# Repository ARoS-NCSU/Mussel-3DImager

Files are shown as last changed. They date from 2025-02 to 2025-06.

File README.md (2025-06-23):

# Mussel 3D Imager

We leverage advanced 3D reconstruction techniques to enhance the accuracy of AI-based mussel analysis. Specifically, we utilize Neural Radiance Fields (NeRF), a cutting-edge 3D reconstruction tool, to generate detailed 3D models of mussel valve configurations and behavioral patterns. NeRF reconstructs 3D scenes and objects from a sparse set of 2D images.

To facilitate image capture, we developed a custom data collection system capable of imaging mussels from multiple angles. This system includes a turntable constructed from foam board, marked along the edges for reference, with a central mounting area for the mussels. A servo motor, controlled by an ESP32 microcontroller, rotates the turntable in small increments, while an ESP32 camera captures images at each step. The captured images, along with rotation degree data and timestamps, are stored on a Secure Digital (SD) card.

Additionally, several key components, such as the camera holder and turntable base, are 3D-printed. The collected images are then used to train a NeRF model using the Python-based Nerfstudio framework, and the generated 3D models can be visualized through the Nerfstudio API.

## Assembly Instructions:

You will need: 

1. A 1/2" PVC pipe
2. 3/16" thick foam baord to construct base plate 
3. Printed 3D parts, located in the 3D Parts folder

Construct the base plate by cutting a 1ft diameter circle out of the foam board. Create the rim for the plate by cutting out a 3.5in by 3ft rectangle. Score it with a blade to allow it to form a ring as seen in the image below. Attach the Dis+Base+Bottom part to the bottom of the plate and the Disc+Base+Top file on top of the plate, and secure them together with screws. Glue the arm of the Servo motor to the center of the Dis+Base+Bottom part. place the servo into the slot in the Base+Part+1 part. 

The Base+Part+1 and Base+Part+2 should be secured to a surface using tape or clamps when running, as they will topple over if not secured. 

ESP32 Mount Instructions:

Super glue the ESP32+-+Joint+Attachment to the back of the ESP32+-+Mount. The PVC+Suport+with+Connector should fit snugly into the gap of the ESP32+-+Joint+Attachment. Use a screw and a nut to keep it in place. The ESP32 Mount should be able to rotate tightly. Attach it to the PVC pipe, using zip ties to keep it secure. 

Read the README_code.txt file for instructions on programming.

## 3D reconstruction instructions using NeRFStudio:
This section provides instructions for performing 3D reconstruction using Nerfstudio.
### Installation
To set up the environment, follow the installation instructions from the official Nerfstudio documentation: https://docs.nerf.studio/quickstart/installation.html
### Data Processing
Once installed, process your image dataset by running the following command:
```bash
ns-process-data images --data {DATA_PATH} --output-dir {PROCESSED_DATA_DIR}
```
Replace {DATA_PATH} with the path to your dataset and {PROCESSED_DATA_DIR} with the desired output directory for processed data.
### Training
Train the Nerfacto model using the processed data:
```bash
ns-train nerfacto --data {PROCESSED_DATA_DIR}
```
### Evaluation
To evaluate the trained model, use the following command:
```bash
ns-eval --load-config={PATH_TO_CONFIG} --output-path=output.json
```
Replace {PATH_TO_CONFIG} with the path to your configuration file.
### Results
The evaluation results will be saved in output.json.

For more details, refer to the Nerfstudio documentation.
## Mussel 3D reconstruction Output:
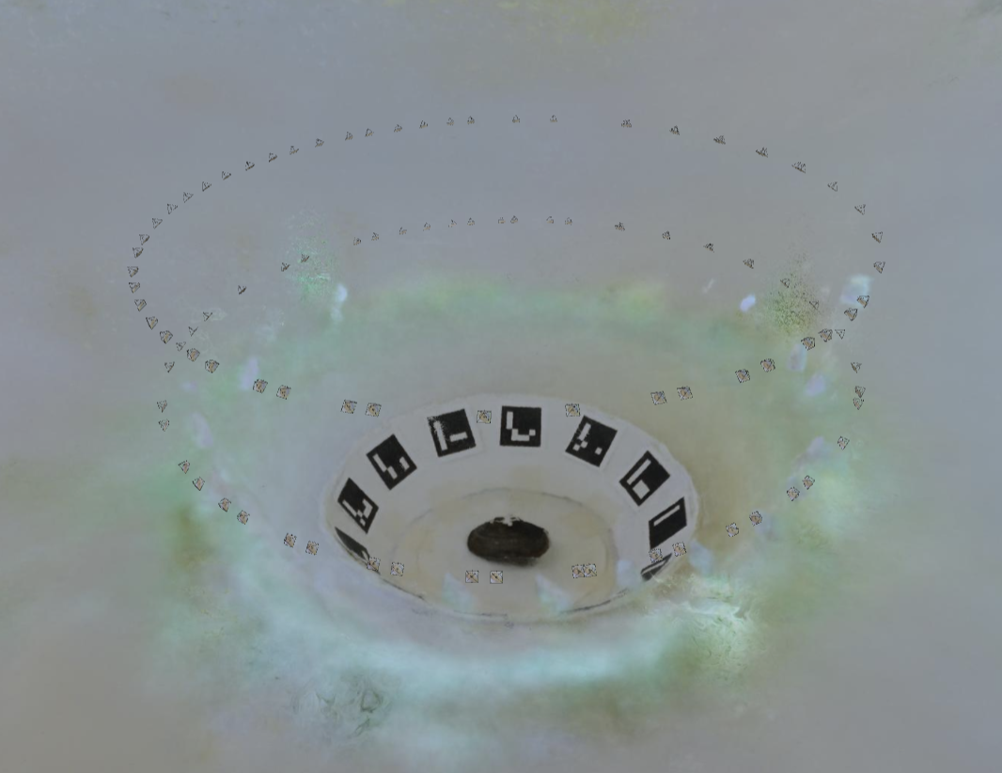
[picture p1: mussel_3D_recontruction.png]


## ESP32 based imaging system:
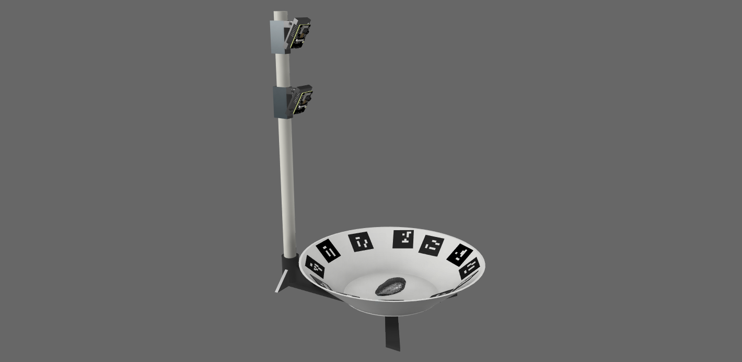
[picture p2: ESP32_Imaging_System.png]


## Mussel ESP32 3D Reconstruction
Video - https://www.youtube.com/watch?v=Asff8yX_VgY

## Citation

If you use this work in your research, please cite:

```bibtex
@inproceedings{sanap2025ai,
  author    = {Mayur Sanap and Arman Badalamenti and Devadharshini Ayyappan and Sanjana Banerjee and Diana Milena Urieta and Caren Cooper and Michael Daniele and James Reynolds and Jay F. Levine and Alper Bozkurt and Edgar Lobaton},
  title     = {AI-Driven Mussel Behavior Monitoring Using an Accessible 3D Imaging System},
  booktitle = {Proceedings of the 2025 ASEE Annual Conference \& Exposition},
  year      = {2025},
  address   = {Montreal, QC},
  month     = {June 22--25},
  organization = {ASEE}
}
```

## Contact Us

If you have any questions or suggestions, feel free to reach out:

- Mayur Sanap - msanap@ncsu.edu
- Dr. Edgar Lobaton - edgar.lobaton@ncsu.edu

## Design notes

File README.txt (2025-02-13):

-------- INTRODUCTION --------

The 'ESP32_cam_google_drive.ino' file folder will allow you to run a program on your ESP32-CAM that will connect your ESP32-CAM to the internet, connect to google, periodically take photos and send them to a google drive folder. 'The ESP32_cam_google_drive_and_servo_motor.ino' file folder does the same thing, except it also rotates a servo motor between taking photos. 

The 'ESP32_CAM_GS.txt' file is a google script that will allow the ESP32-CAM to save photos directly to your google drive. 

-------- SET UP --------

Before running the .ino files, you must create the google script. To do this, do the following. 

1. Go to https://script.google.com/home/

2. Click 'New Project'

3. Paste the contents of 'ESP32_CAM_GS.txt' into the code space. Edit the time zone to yours and change the value of the folderName constant to the name of the folder in google derive that you would like to save your photos to. 

4. Click 'Deploy,' then click 'New Deployment.'

5. Select type 'Web App,' then change Who has access to 'Anyone.'

6. Click Deploy and authorize with your google id when prompted. 

7. Copy the deployment ID. This will be used in the .ino scripts

-------- RUNNING THE INO FILES --------

Save the the 'ESP32_cam_google_drive_and_servo_motor.ino' and 'ESP32_cam_google_drive.ino' file folders to your local device and open them using your IDE. In the .ino files, find the following lines of code:

const char* ssid = "****";
const char* password = "****";

ssid shold be set to your networks ssid and password should be set to your network's password. 

Below that, there will be the following lines of code:

String myDeploymentID = "Deployment ID";
String myMainFolderName = "Folder Name";

Paste your google script's deployment ID and the corresponding folder name.

Upload the two projects to two different ESP32-CAMs

-------- CONNECTINGE THE SERVO --------

The ESP32-CAM that the 'ESP32_cam_google_drive_and_servo_motor.ino' file was uploaded to should be connected to a micro servo motor. Connect the servo's positive wire to the ESP32-CAM's 3.3V pin, connect the servo's ground wire to the ESP32-CAM's ground pin, and connect the servo's signal pin to GPIO pin 13. 

-------- RUNNING THE CODE --------

The code will run automatically when connected to power and start taking photos and sending them to google drive.

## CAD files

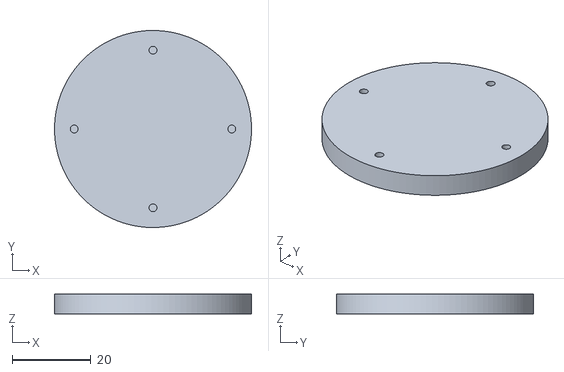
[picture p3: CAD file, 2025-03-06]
3D Parts/Disk+Base+Top.stl
50.0 x 50.0 x 5.00

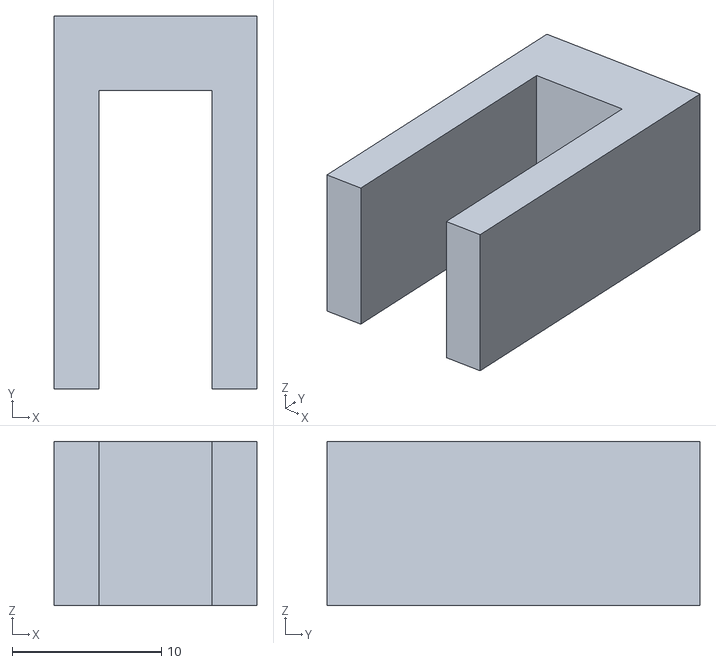
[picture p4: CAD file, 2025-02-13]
3D Parts/ESP32+-+Clip+-+Top.stl
13.6 x 25.0 x 11.0

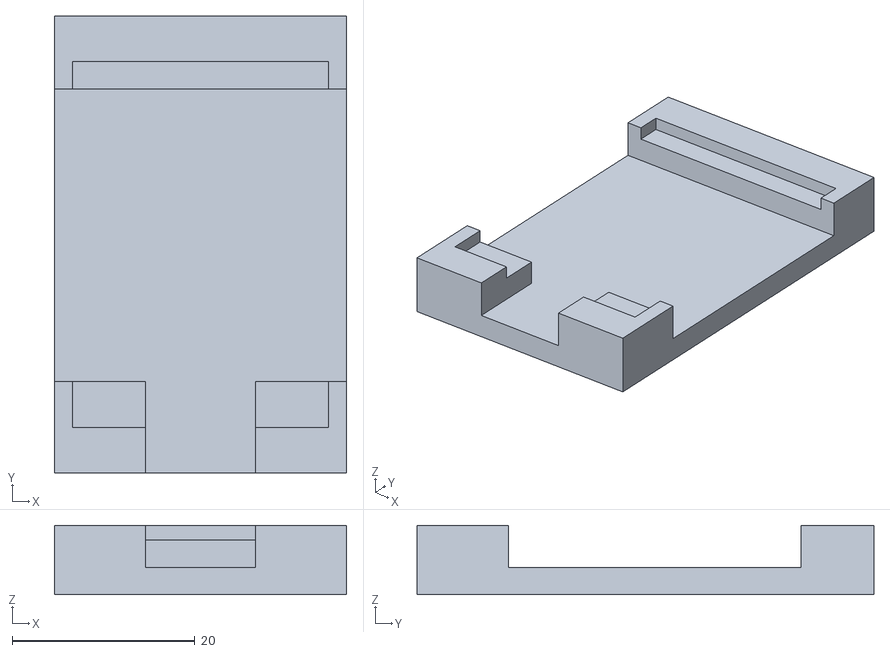
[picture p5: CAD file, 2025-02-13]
3D Parts/ESP32+-+Mount.stl
32.0 x 50.0 x 7.60

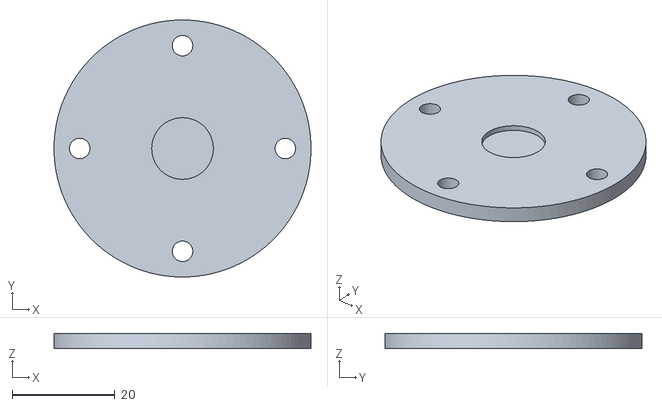
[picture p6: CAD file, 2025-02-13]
3D Parts/Disc+Base+Bottom.stl
50.0 x 50.0 x 3.00

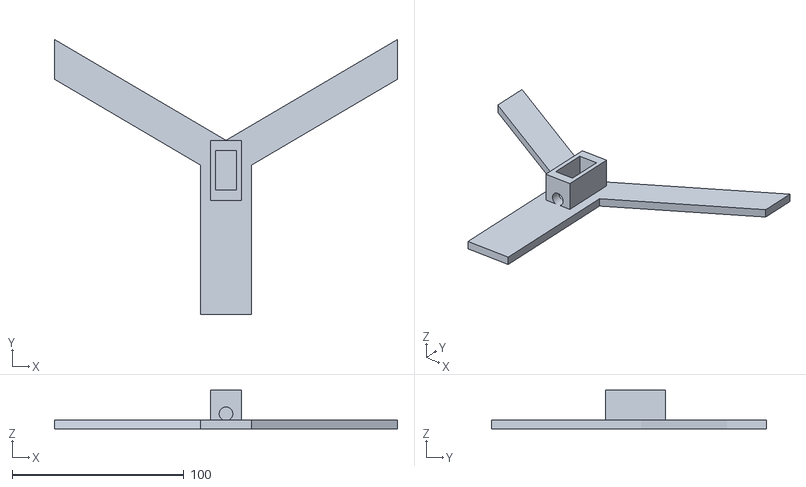
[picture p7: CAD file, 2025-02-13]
3D Parts/Base+Part+1.stl
200.0 x 160.4 x 22.5

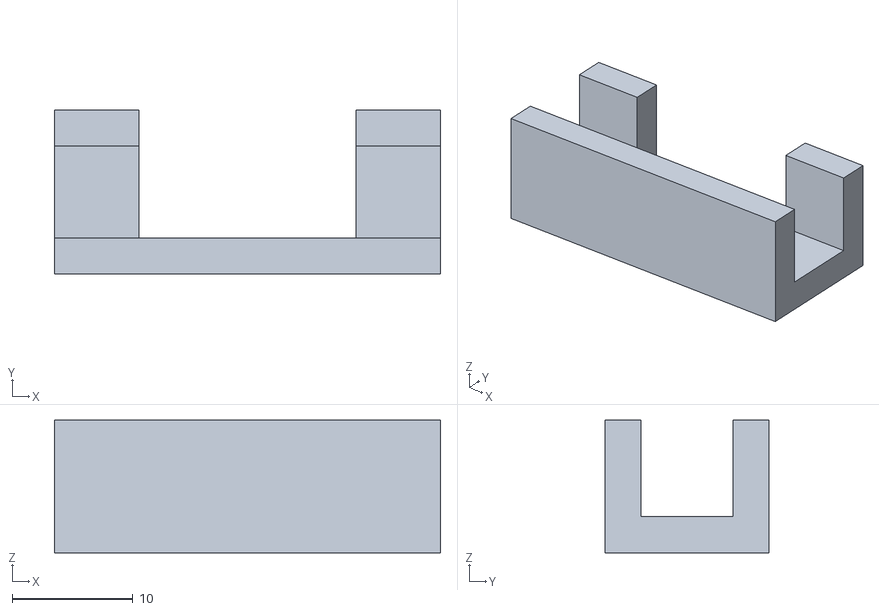
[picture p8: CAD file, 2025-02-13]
3D Parts/ESP32+-+Clip+-+Bottom.stl
32.0 x 13.6 x 11.0

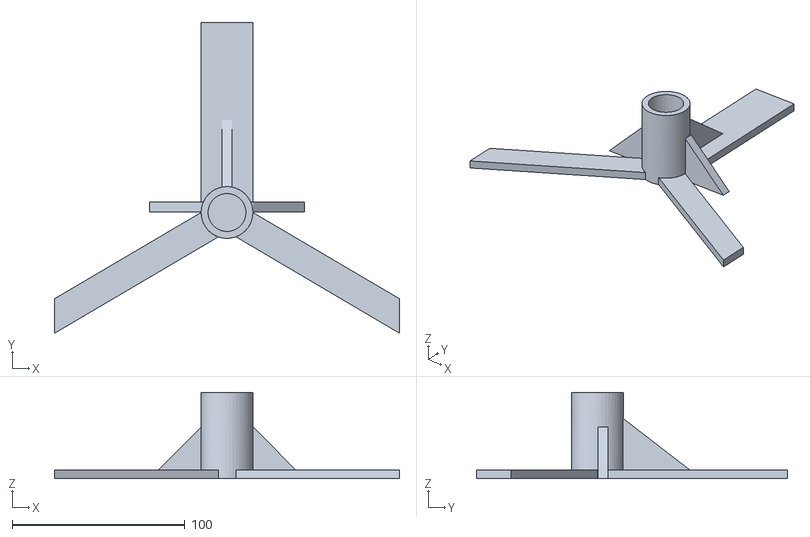
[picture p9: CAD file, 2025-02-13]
3D Parts/Base+Part+2.stl
200.0 x 180.0 x 50.0

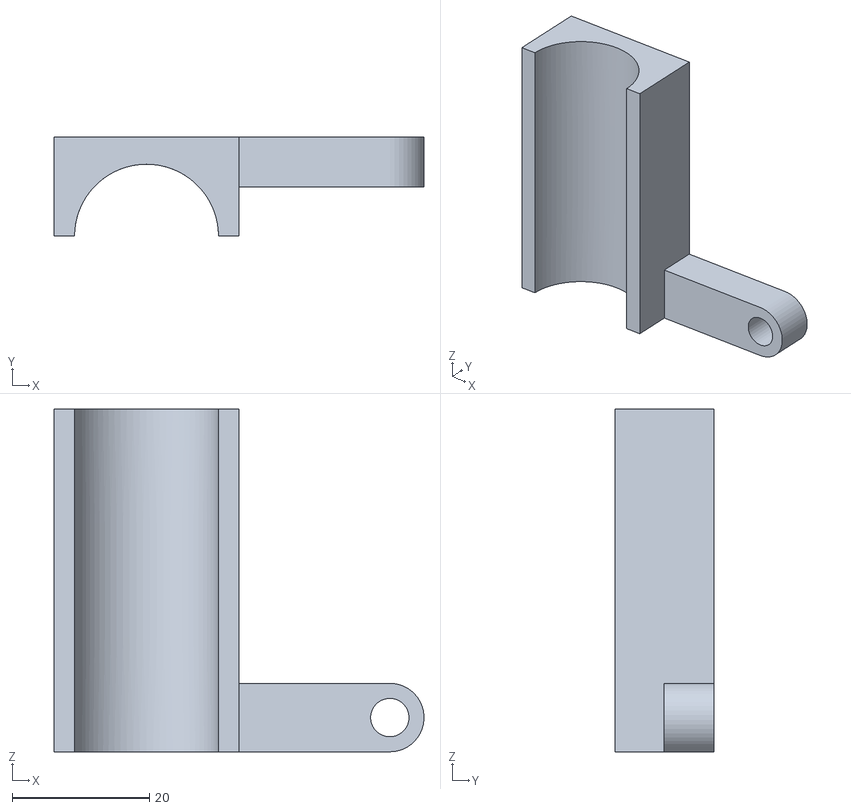
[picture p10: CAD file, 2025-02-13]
3D Parts/PVC+Suport+with+Connector.stl
54.0 x 14.5 x 50.0

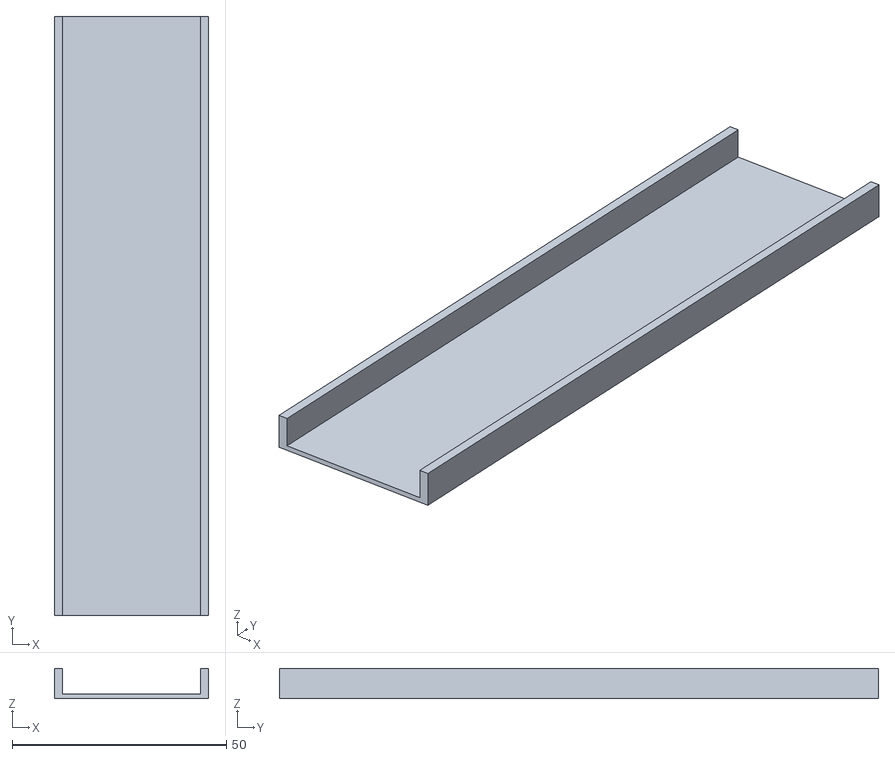
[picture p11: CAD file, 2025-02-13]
3D Parts/Base+Tray.stl
36.0 x 139.6 x 7.00

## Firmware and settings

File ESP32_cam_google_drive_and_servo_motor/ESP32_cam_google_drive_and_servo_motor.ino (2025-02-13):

//======================================== Included libraries and files
#include <WiFi.h>
#include <WiFiClientSecure.h>
#include <ESP32Servo.h>
#include "soc/soc.h"
#include "soc/rtc_cntl_reg.h"
#include "Base64.h"
#include "esp_camera.h"

//======================================== Define pins
#define PWDN_GPIO_NUM     32
#define RESET_GPIO_NUM    -1
#define XCLK_GPIO_NUM      0
#define SIOD_GPIO_NUM     26
#define SIOC_GPIO_NUM     27

#define Y9_GPIO_NUM       35
#define Y8_GPIO_NUM       34
#define Y7_GPIO_NUM       39
#define Y6_GPIO_NUM       36
#define Y5_GPIO_NUM       21
#define Y4_GPIO_NUM       19
#define Y3_GPIO_NUM       18
#define Y2_GPIO_NUM        5
#define VSYNC_GPIO_NUM    25
#define HREF_GPIO_NUM     23
#define PCLK_GPIO_NUM     22
#define SERVO_1           13
#define TURN_TIME         82    // TURN_TIME is time in ms servo will rotate for
#define SERVO_STOP        95    // Servo Stops when 95 is written to it
#define SERVO_MOVE        60    // Value between 0 and 95. Closer to 0 rotates faster 

//======================================== 

#define FLASH_LED 4


Servo servo1;                 // Create Servo object

//======================================== Enter your WiFi ssid and password.
const char* ssid = "****";
const char* password = "****";
//======================================== 

//======================================== Replace with your "Deployment ID" and Folder Name.
String myDeploymentID = "Deployment ID";
String myMainFolderName = "Folder Name";
//======================================== 

//======================================== Variables for Timer/Millis.
unsigned long previousMillis = 0; 
const int Interval = 20000; //--> Capture and Send a photo every 20 seconds.
//======================================== 

// Variable to set capture photo with LED Flash.
// Set to "false", then the Flash LED will not light up when capturing a photo.
// Set to "true", then the Flash LED lights up when capturing a photo.
bool LED_Flash_ON = false;

// Initialize WiFiClientSecure.
WiFiClientSecure client;

//________________________________________________________________________________ Test_Con()
// This subroutine is to test the connection to "script.google.com".
void Test_Con() {
  const char* host = "script.google.com";
  while(1) {
    Serial.println("-----------");
    Serial.println("Connection Test...");
    Serial.println("Connect to " + String(host));
  
    client.setInsecure();
  
    if (client.connect(host, 443)) {
      Serial.println("Connection successful.");
      Serial.println("-----------");
      client.stop();
      break;
    } else {
      Serial.println("Connected to " + String(host) + " failed.");
      Serial.println("Wait a moment for reconnecting.");
      Serial.println("-----------");
      client.stop();
    }
  
    delay(1000);
  }
}
//________________________________________________________________________________ 




//________________________________________________________________________________ SendCapturedPhotos()
// Subroutine for capturing and sending photos to Google Drive.
void SendCapturedPhotos() {
  const char* host = "script.google.com";
  Serial.println();
  Serial.println("-----------");
  Serial.println("Connect to " + String(host));
  
  client.setInsecure();

  //---------------------------------------- The Flash LED blinks once to indicate connection start.
  digitalWrite(FLASH_LED, HIGH);
  delay(100);
  digitalWrite(FLASH_LED, LOW);
  delay(100);
  //---------------------------------------- 

  //---------------------------------------- The process of connecting, capturing and sending photos to Google Drive.
  if (client.connect(host, 443)) {
    Serial.println("Connection successful.");
    
    if (LED_Flash_ON == true) {
      digitalWrite(FLASH_LED, HIGH);
      delay(100);
    }

    //.............................. Taking a photo.
    Serial.println();
    Serial.println("Taking a photo...");
    
    for (int i = 0; i <= 3; i++) {
      camera_fb_t * fb = NULL;
      fb = esp_camera_fb_get();
       if(!fb) {
          Serial.println("Camera capture failed");
          Serial.println("Restarting the ESP32 CAM.");
          delay(1000);
          ESP.restart();
          return;
        } 
      esp_camera_fb_return(fb);
      delay(200);
    }
  
    camera_fb_t * fb = NULL;
    fb = esp_camera_fb_get();
    if(!fb) {
      Serial.println("Camera capture failed");
      Serial.println("Restarting the ESP32 CAM.");
      delay(1000);
      ESP.restart();
      return;
    } 
  
    if (LED_Flash_ON == true) digitalWrite(FLASH_LED, LOW);
    
    Serial.println("Taking a photo was successful.");

    //.............................. 

    //.............................. Sending image to Google Drive.
    Serial.println();
    Serial.println("Sending image to Google Drive.");
    Serial.println("Size: " + String(fb->len) + "byte");
    
    String url = "/macros/s/" + myDeploymentID + "/exec?folder=" + myMainFolderName;

    client.println("POST " + url + " HTTP/1.1");
    client.println("Host: " + String(host));
    client.println("Transfer-Encoding: chunked");
    client.println();

    int fbLen = fb->len;
    char *input = (char *)fb->buf;
    int chunkSize = 3 * 1000; //--> must be multiple of 3.
    int chunkBase64Size = base64_enc_len(chunkSize);
    char output[chunkBase64Size + 1];

    Serial.println();
    int chunk = 0;
    for (int i = 0; i < fbLen; i += chunkSize) {
      int l = base64_encode(output, input, min(fbLen - i, chunkSize));
      client.print(l, HEX);
      client.print("\r\n");
      client.print(output);
      client.print("\r\n");
      delay(100);
      input += chunkSize;
      Serial.print(".");
      chunk++;
      if (chunk % 50 == 0) {
        Serial.println();
      }
    }
    client.print("0\r\n");
    client.print("\r\n");

    esp_camera_fb_return(fb);
    //.............................. 

    //.............................. Waiting for response.
    Serial.println("Waiting for response.");
    long int StartTime = millis();
    while (!client.available()) {
      Serial.print(".");
      delay(100);
      if ((StartTime + 10 * 1000) < millis()) {
        Serial.println();
        Serial.println("No response.");
        break;
      }
    }
    Serial.println();
    while (client.available()) {
      Serial.print(char(client.read()));
    }
    //.............................. 

    //.............................. Flash LED blinks once as an indicator of successfully sending photos to Google Drive.
    digitalWrite(FLASH_LED, HIGH);
    delay(500);
    digitalWrite(FLASH_LED, LOW);
    delay(500);
    //.............................. 
  }
  else {
    Serial.println("Connected to " + String(host) + " failed.");
    
    //.............................. Flash LED blinks twice as a failed connection indicator.
    digitalWrite(FLASH_LED, HIGH);
    delay(500);
    digitalWrite(FLASH_LED, LOW);
    delay(500);
    digitalWrite(FLASH_LED, HIGH);
    delay(500);
    digitalWrite(FLASH_LED, LOW);
    delay(500);
    //.............................. 
  }
  //---------------------------------------- 

  Serial.println("-----------");

  client.stop();
}
//________________________________________________________________________________ 

//________________________________________________________________________________ VOID SETUP()
void setup() {
  // put your setup code here, to run once:
  
  // Disable brownout detector.
  servo1.attach(SERVO_1);
  WRITE_PERI_REG(RTC_CNTL_BROWN_OUT_REG, 0);
  
  Serial.begin(115200);
  Serial.println();
  delay(1000);

  pinMode(FLASH_LED, OUTPUT);
  
  // Setting the ESP32 WiFi to station mode.
  Serial.println();
  Serial.println("Setting the ESP32 WiFi to station mode.");
  WiFi.mode(WIFI_STA);

  //---------------------------------------- The process of connecting ESP32 CAM with WiFi Hotspot / WiFi Router.
  Serial.println();
  Serial.print("Connecting to : ");
  Serial.println(ssid);
  WiFi.begin(ssid, password);
  
  // The process timeout of connecting ESP32 CAM with WiFi Hotspot / WiFi Router is 20 seconds.
  // If within 20 seconds the ESP32 CAM has not been successfully connected to WiFi, the ESP32 CAM will restart.
 
  int connecting_process_timed_out = 40; //--> 20 = 20 seconds.
  connecting_process_timed_out = connecting_process_timed_out * 2;
  while (WiFi.status() != WL_CONNECTED) {
    Serial.print(".");
    digitalWrite(FLASH_LED, HIGH);
    delay(250);
    digitalWrite(FLASH_LED, LOW);
    delay(250);
    if(connecting_process_timed_out > 0) connecting_process_timed_out--;
    if(connecting_process_timed_out == 0) {
      Serial.println();
      Serial.print("Failed to connect to ");
      Serial.println(ssid);
      Serial.println("Restarting the ESP32 CAM.");
      delay(1000);
      ESP.restart();
    }
  }

  digitalWrite(FLASH_LED, LOW);
  
  Serial.println();
  Serial.print("Successfully connected to ");
  Serial.println(ssid);
  //Serial.print("ESP32-CAM IP Address: ");
  //Serial.println(WiFi.localIP());
  //---------------------------------------- 

  //---------------------------------------- Set the camera ESP32 CAM.
  Serial.println();
  Serial.println("Set the camera ESP32 CAM...");
  
  camera_config_t config;
  config.ledc_channel = LEDC_CHANNEL_0;
  config.ledc_timer = LEDC_TIMER_0;
  config.pin_d0 = Y2_GPIO_NUM;
  config.pin_d1 = Y3_GPIO_NUM;
  config.pin_d2 = Y4_GPIO_NUM;
  config.pin_d3 = Y5_GPIO_NUM;
  config.pin_d4 = Y6_GPIO_NUM;
  config.pin_d5 = Y7_GPIO_NUM;
  config.pin_d6 = Y8_GPIO_NUM;
  config.pin_d7 = Y9_GPIO_NUM;
  config.pin_xclk = XCLK_GPIO_NUM;
  config.pin_pclk = PCLK_GPIO_NUM;
  config.pin_vsync = VSYNC_GPIO_NUM;
  config.pin_href = HREF_GPIO_NUM;
  config.pin_sscb_sda = SIOD_GPIO_NUM;
  config.pin_sscb_scl = SIOC_GPIO_NUM;
  config.pin_pwdn = PWDN_GPIO_NUM;
  config.pin_reset = RESET_GPIO_NUM;
  config.xclk_freq_hz = 20000000;
  config.pixel_format = PIXFORMAT_JPEG;
  
  // init with high specs to pre-allocate larger buffers
  if(psramFound()){
    config.frame_size = FRAMESIZE_UXGA;
    config.jpeg_quality = 10;  //0-63 lower number means higher quality
    config.fb_count = 2;
  } else {
    config.frame_size = FRAMESIZE_SVGA;
    config.jpeg_quality = 8;  //0-63 lower number means higher quality
    config.fb_count = 1;
  }
  
  // camera init
  esp_err_t err = esp_camera_init(&config);
  if (err != ESP_OK) {
    Serial.printf("Camera init failed with error 0x%x", err);
    Serial.println();
    Serial.println("Restarting the ESP32 CAM.");
    delay(1000);
    ESP.restart();
  }

  sensor_t * s = esp_camera_sensor_get();

  // Selectable camera resolution details :
  // -UXGA   = 1600 x 1200 pixels
  // -SXGA   = 1280 x 1024 pixels
  // -XGA    = 1024 x 768  pixels
  // -SVGA   = 800 x 600   pixels
  // -VGA    = 640 x 480   pixels
  // -CIF    = 352 x 288   pixels
  // -QVGA   = 320 x 240   pixels
  // -HQVGA  = 240 x 160   pixels
  // -QQVGA  = 160 x 120   pixels
  s->set_framesize(s, FRAMESIZE_SXGA);  //--> UXGA|SXGA|XGA|SVGA|VGA|CIF|QVGA|HQVGA|QQVGA

  Serial.println("Setting the camera successfully.");
  Serial.println();

  delay(1000);

  Test_Con();

  Serial.println();
  Serial.println("ESP32-CAM captures and sends photos to the server every 20 seconds.");
  Serial.println();
  delay(2000);
}
//________________________________________________________________________________ 

//________________________________________________________________________________ VOID LOOP()
void loop() {
  // put your main code here, to run repeatedly:

  //---------------------------------------- Timer/Millis to capture and send photos to Google Drive every 20 seconds (see Interval variable).
  unsigned long currentMillis = millis();
  if (currentMillis - previousMillis >= Interval) {
    previousMillis = currentMillis;

    SendCapturedPhotos();

    servo1.write(SERVO_MOVE);   // Servo rotates at specified speed
    delay(TURN_TIME);           // Servo continues rotating for specified time
    servo1.write(SERVO_STOP);   // Servo Stops 
    Serial.println();
    Serial.println("Motor Moved");
    Serial.println();

  }
  //---------------------------------------- 
}
//________________________________________________________________________________ 
//<<<<<<<<<<<<<<<<<<<<<<<<<<<<<<<<<<<<<<<<<<<<<<<<<<<<<<<<<<<<<<<<<<<<<<<<<<<<<<<<<<<<<<<<<

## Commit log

2025-02-13 Rename Base+Part+1.stl to 3D Parts/Base+Part+1.stl
    [Base+Part+1.stl]
2025-02-13 Rename Base+Part+2.stl to 3D Parts/Base+Part+2.stl
    [Base+Part+2.stl]
2025-02-13 Rename Base+Tray.stl to 3D Parts/Base+Tray.stl
    [Base+Tray.stl]
2025-02-13 Rename Disc+Base+Bottom+v1.stl to 3D Parts/Disc+Base+Bottom+v1.stl
    [Disc+Base+Bottom+v1.stl]
2025-02-13 Rename ESP32+-+Clip+-+Bottom+v2.stl to 3D Parts/ESP32+-+Clip+-+Bottom+v2.stl
    [ESP32+-+Clip+-+Bottom+v2.stl]
2025-02-13 Rename ESP32+-+Clip+-+Top+v1.stl to 3D Parts/ESP32+-+Clip+-+Top+v1.stl
    [ESP32+-+Clip+-+Top+v1.stl]
2025-02-13 Rename ESP32+-+Joint+Attachment+v1.stl to 3D Parts/ESP32+-+Joint+Attachment+v1.stl
    [ESP32+-+Joint+Attachment+v1.stl]
2025-02-13 Rename ESP32+-+Mount+v1.stl to 3D Parts/ESP32+-+Mount+v1.stl
    [ESP32+-+Mount+v1.stl]
2025-02-13 Rename PVC+Suport+with+Connector+v1 (1).stl to 3D Parts/PVC+Suport+with+Connector+v1 (1).stl
    [PVC+Suport+with+Connector+v1 (1).stl]
2025-02-13 Update and rename Base64.cpp to ESP32_cam_google_drive/Base64.cpp
2025-02-13 Update and rename ESP32_cam_google_drive/Base64.cpp to ESP32_cam_google_drive/ESP32_cam_google_drive/Base64.cpp
2025-02-13 Update and rename ESP32_cam_google_drive/ESP32_cam_google_drive/Base64.cpp to ESP32_cam_google_drive/Base64.cpp
2025-02-13 Update and rename Base64.h to ESP32_cam_google_drive/Base64.h
2025-02-13 Rename ESP32+-+Joint+Attachment+v1 (1).stl to ESP32+-+Joint+Attachment.stl
    [ESP32+-+Joint+Attachment.stl]
2025-02-13 Rename PVC+Suport+with+Connector+v1 (1).stl to PVC+Suport+with+Connector+v1.stl
    [PVC+Suport+with+Connector+v1.stl]
2025-03-06 Rename Disk Base Top.stl to Disk+Base+Top.stl
    [Disk+Base+Top.stl]
